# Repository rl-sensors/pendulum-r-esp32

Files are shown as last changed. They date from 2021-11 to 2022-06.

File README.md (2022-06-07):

# Real-world Implementation of the Swing Up Pendulum

This is an implementation of the swing up pendulum for [ESP32S2](https://www.sparkfun.com/products/17743) board for Deep Reinforcement Learning training.

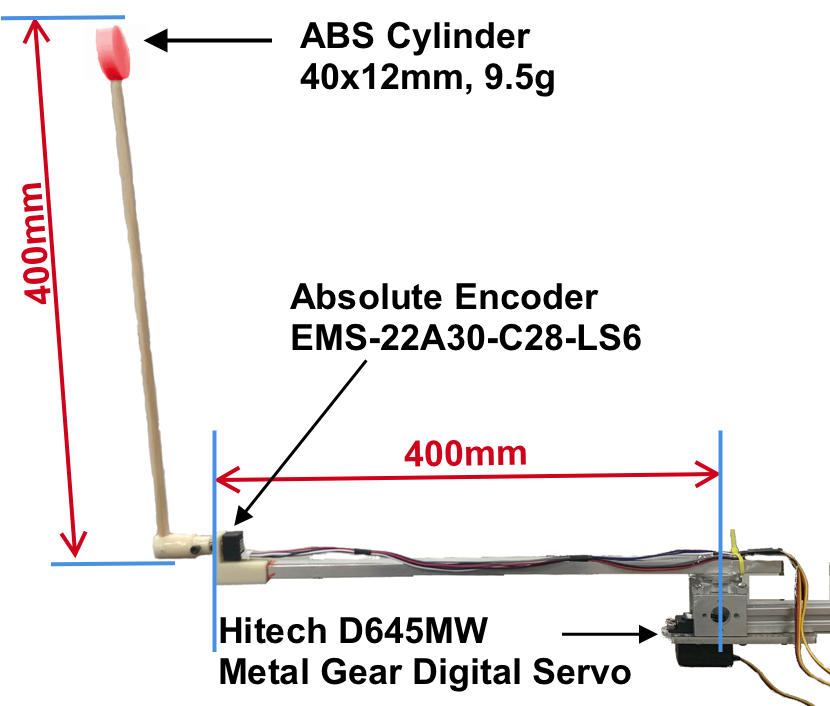
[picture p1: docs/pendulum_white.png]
Pendulum


The CAD file with parts to be 3D printed is in [docs folder](docs/pendulum_r_sim.FCStd) (requires FreeCAD). They are encoder mount, pendulum coupler and the weight cylinder. 
We used ABS filament with 100% in-fill. Despite that, both the encoder mount and the coupler broke during the experiments.

The arm is made of aluminium rectangle tube 20x10x2mm and the pendulum is made of 8mm pine dowel.

The servo is mounted using a servo block - [they are available in the US](https://www.gobilda.com/servoblock-standard-size-25-tooth-spline-hub-shaft/) - we used a custom made block.

### Communication with DRL Training
It uses MQTT protocol for communication (over WiFi).
The observations are streamed to `pendulum-r/obs/r01` and the actions need to be streamed to `pendulum-r/act/r01`.

### Building and Uploading
This is a [PlatformIO](https://platformio.org) project, so it requires platformIO to be installed.

Because the ESP32S2 is not yet fully supported, it requires a custom toolchain. 

For platformIO, find the toolchain in the [JSON file](https://raw.githubusercontent.com/espressif/arduino-esp32/gh-pages/package_esp32_index.json) from the __Installing using Boards Manager__ section.
Look for section `xtensa-esp32s2-elf-gcc` and download the toolchain for your platform.

Untar the file and copy the above JSON file inside and rename it to `package.json`.

Update the `platformio.ini` file to include:

    board_build.mcu = esp32s2
    platform_packages =
        toolchain-xtensa32s2@file:///home/xxx/install/xtensa-esp32s2-elf
        framework-arduinoespressif32@https://github.com/espressif/arduino-esp32.git#44c11981d2159565c551028f2498f65764607f74
        platformio/tool-esptoolpy @ ~1.30100

Basically, the toolchain-xtensa32s2 points to the dir with the downloaded toolchain.

The `framework-arduinoespressif32` section points to the github (the #44c11 is hash of version 2.0)

After that it's just:

    pio project init
    platformio run --target upload -e esp32thing_plus

Alternatively, you can use one of the supported IDEs like CLion or Visual Studio.

## Code
### Main
We are using Arduino rather than ESP-IDF (because the original version use Teensy 4.0), there are 2 main methods - `setup()` and `loop()`.
The first runs initialization code and the second is called repeatedly.

### Encoder
The encoder used is a low cost absolute encoder [EMS-22A30-C28-LS6](https://www.digikey.com/en/products/detail/bourns-inc/EMS22A30-C28-LS6/3693519).
It requires custom protocol for reading the values. It is implemented in [BournsEncoder.h](include/BournsEncoder.h).
The final reading used for training is mean of the last 3 readings (implemented through circular buffer).

### Servo Shield
The servo [Hitec D645MW](https://hitecrcd.com/products/servos/sport-servos/digital-sport-servos/d645mw/product) is controlled through [servo shield](https://www.adafruit.com/product/815).
This allows the MCU and servo to be powered separately and protect the MCU when servo fails (which does happen every few hundreds hours of operation).

We experimented with different servos - with varying success. The D645MW is very smooth and has a good holding torque and it's quite durable.
We were able to train with Turnigy TGY-WP23 as well but it oscillates and breaks quite fast.
We also tried [HSB-9380TH](https://hitecrcd.com/products/servos/digital/brushless-digital/hsb-9380th-ultra-torque-brushless-titanium-gear-servo/product) but it was not possible to even start training because it developed powerful oscillation.

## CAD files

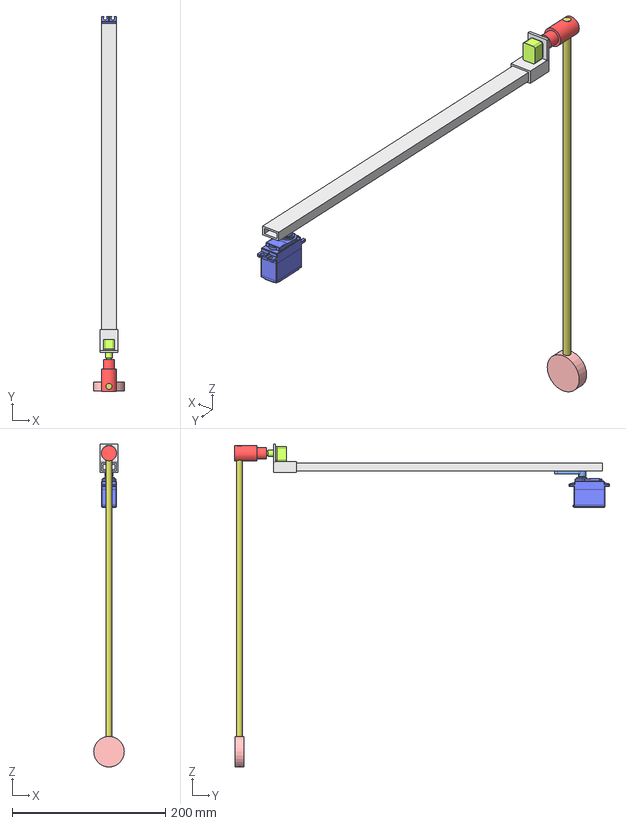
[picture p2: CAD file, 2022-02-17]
docs/pendulum_r_sim.FCStd
40.0 x 490.5 x 422.0 mm
Arm
HS-488HB
EMS22A30
PendulumMount
Dowel
PendulumWeight
EncoderMount

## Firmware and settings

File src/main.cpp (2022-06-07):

#include <Arduino.h>
#include "ServoShield.h"
#include "BournsEncoder.h"
#include <Wire.h>

#include <WiFi.h>
#include <MQTT.h>

const char ssid[] = "smc6";
const char pass[] = "nejaketazkeheslo";
const char mqt_ip[] = "192.168.86.202";

WiFiClient net;
MQTTClient client;

String showText;
int position_update = 0;
unsigned long lastMillis = 0;
int lastPosition = 0;

unsigned long dataSentTS, lastActionTS = millis();
int encoder_offset = 31; // with the ABS coupler (with the line)

bool sendData = false;
bool autoSendData = false;
bool continuousActionSpace = false;

constexpr float throttleSpeed = 2.0;

int streaming_delay = 25;
int acting_delay = 10;

constexpr int setupNo = 1;

String observationsTopic = String("pendulum-r/obs/r0") + setupNo;
String actionsTopic = String("pendulum-r/act/r0") + setupNo;

void connect();
void getBTData(String &topic, String &payload);

void setup() {
  Serial.begin(115200);
  delay(2000);
  Serial.println("Starting...");

  Wire.begin(1, 2); // ESP32S2
  Wire.setClock(400000);

  WiFi.begin(ssid, pass);

  ServoShield::init();
//  BournsEncoder::init(32, 15, 33); // ESP32
//   BournsEncoder::init(8, 4, 6); //ESP32S2 - P2
  BournsEncoder::init(6, 8, 10); //ESP32S2 - P1

  // Note: Local domain names (e.g. "Computer.local" on OSX) are not supported
  // by Arduino. You need to set the IP address directly.
  client.begin(mqt_ip, net);
  client.onMessage(getBTData);

  connect();

  Serial.print("Listening on ");
  Serial.println(actionsTopic);
  Serial.print("Observations on ");
  Serial.println(observationsTopic);
}

void loop() {
  client.loop();
  // delay(1);  // <- fixes some issues with WiFi stability

  unsigned long newMillis = millis();

  // this block takes about 5ms
  if ((sendData || (autoSendData && (newMillis - dataSentTS > streaming_delay)))) {
    // this call takes 3ms
    BournsEncoder::read();
    // Serial.print("Bourns reading took: ");
    // Serial.println(millis() - newMillis);

    int time_delta = (int) (newMillis - lastMillis);
    lastMillis = newMillis;

    int position = (BournsEncoder::position + encoder_offset) % 1024;
    float velocity = (position - lastPosition) / time_delta;
    lastPosition = position;

    char state[100] = ""; // without the initialization it contains new lines and unprintable chars
    sprintf(state, "S%ld,%d,%d,%f,%f,%f",
            newMillis,
            position,
            ServoShield::pulselen,
            BournsEncoder::omegas.average(),
            BournsEncoder::acceleration,
            velocity
    );

    Serial.println(state);
    client.publish(observationsTopic, state);
    dataSentTS = newMillis;

    if (sendData) {
      sendData = false;
    }

     // Serial.print("Sending data took: ");
     // Serial.println(millis() - newMillis);
  }

  newMillis = millis();
  // throttle when omega is over 2 rotations per second
  if (!continuousActionSpace && newMillis - lastActionTS > acting_delay) {
    if (fabs(BournsEncoder::omegas.average()) > throttleSpeed) {
      position_update = ServoShield::STOP;
    }
    ServoShield::move(position_update);
    lastActionTS = newMillis;
  }
}

void connect() {
  Serial.print("checking wifi...");
  while (WiFi.status() != WL_CONNECTED) {
    Serial.print(".");
    delay(1000);
  }

  String clientId = String("pendulum_r_prod_s") + setupNo;

  Serial.print("\nconnecting...");
  while (!client.connect(clientId.c_str(), "public", "public")) {
    Serial.print(".");
    delay(1000);
  }

  Serial.println("\nconnected!");

  client.subscribe(actionsTopic);
}


void getBTData(String &topic, String &payload) {
  Serial.print("Received command: ");
  Serial.println(payload);

  char dir = payload.charAt(0);

  switch(dir) {
    case 'a':
      position_update = -ServoShield::FAST;
      break;
    case 's':
      position_update = -ServoShield::SLOW;
      break;
    case 'd':
      position_update = ServoShield::STOP;
      break;
    case 'f':
      position_update = ServoShield::SLOW;
      break;
    case 'g':
      position_update = ServoShield::FAST;
      break;
    case 'm':
      position_update = payload.substring(1).toInt();
      break;
    case 'o':
      encoder_offset = atoi(payload.substring(1).c_str());
      break;
    case 'u':
      streaming_delay = atoi(payload.substring(1).c_str());
      break;
    case 'i':
      acting_delay = atoi(payload.substring(1).c_str());
      break;
    case 'z':
      sendData = true;
      break;
    case 'x':
      autoSendData = true;
      break;
    case 'y':
      autoSendData = false;
      break;
    case 'c':
      continuousActionSpace = true;
      break;
    case 'v':
      continuousActionSpace = false;
      break;
    case 'e':
      ServoShield::EXP_FILTER_C = atof(payload.substring(1).c_str());
      break;
    case 'b':
      if (fabs(BournsEncoder::omegas.average()) <= throttleSpeed) {
        ServoShield::set_action(atof(payload.substring(1).c_str()));
      }
      break;

//      case 'p':
//        showText = cmd.substring(1);
//        Lcd::print_short(showText);
//        break;
    default: break; // keep the current course
  }
}

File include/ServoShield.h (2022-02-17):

//
// Created by bohm on 11/8/21.
//

#ifndef PENDULUM_R_ESP32_SERVOSHIELD_H
#define PENDULUM_R_ESP32_SERVOSHIELD_H

#include <Arduino.h>
#include <Wire.h>
#include <Adafruit_PWMServoDriver.h>

namespace ServoShield {
  Adafruit_PWMServoDriver pwm = Adafruit_PWMServoDriver(0x40);

  #define SERVO_FREQ 50 // Analog servos run at ~50 Hz updates

  // for turnigy 200 and 400
  #define SERVOMIN  200 // This is the 'minimum' pulse length count (out of 4096)
  #define SERVOMAX  400 // This is the 'maximum' pulse length count (out of 4096)

  // for HiTec 9380TH
//  #define SERVOMIN  150 // This is the 'minimum' pulse length count (out of 4096)
//  #define SERVOMAX  450 // This is the 'maximum' pulse length count (out of 4096)
//  #define SERVO_FREQ 50 // Analog servos run at ~50 Hz updates

  // turningy
  static constexpr int  SLOW = 1;
  static constexpr int  FAST = 2;

  float EXP_FILTER_C = 0.9;

    // HiTec
//  static constexpr int  SLOW = 2;
//  static constexpr int  FAST = 4;


  static constexpr int  STOP = 0;

  constexpr uint8_t servonum = 4;

  volatile int pulselen = (SERVOMAX - SERVOMIN) / 2 + SERVOMIN;

  void init() {
    pwm.begin();

    pwm.setPWMFreq(SERVO_FREQ);  // Analog servos run at ~50 Hz updates

    delay(10);

    pwm.setPWM(servonum, 0, pulselen);
  }

  void move(int &position_update) {
    if (pulselen + position_update <= SERVOMAX && pulselen + position_update >= SERVOMIN)  {
      pulselen += position_update;
      //position_update = 0;
    } else {
      //position_update = 0;
    }

    pwm.setPWM(servonum, 0, pulselen);
  }

    void set_position_with_filter(int const &new_position_cmd) {
      int old_position = pulselen;
      int new_position = old_position * EXP_FILTER_C + new_position_cmd * (1.0 - EXP_FILTER_C);
      if (new_position <= SERVOMIN) {
        pulselen = SERVOMIN;
      } else if (new_position >= SERVOMAX) {
        pulselen = SERVOMAX;
      } else {
        pulselen = new_position;
      }

      pwm.setPWM(servonum, 0, pulselen);
    }

    void set_action(float const &new_position_cmd) {
      int position = map(
              new_position_cmd * 1000, -1000.0, 1000.0,
              SERVOMIN, SERVOMAX
      );
      set_position_with_filter(position);

//    char msg[100] = "";
//    sprintf(msg, "Servo %i: action %f translated to position %i", servonum, new_position_cmd, position);
//    Mqtt::client.publish("quaid01/actions", msg);
    }


}

#endif //PENDULUM_R_ESP32_SERVOSHIELD_H

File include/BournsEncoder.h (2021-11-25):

//
// Created by bohm on 11/8/21.
//

#ifndef PENDULUM_R_ESP32_BOURNSENCODER_H
#define PENDULUM_R_ESP32_BOURNSENCODER_H

#include "circular_buffer.h"

namespace BournsEncoder {
  int PIN_CS = 32;
  int PIN_CLOCK = 15;
  int PIN_DATA = 33;

  const int bourns_delay = 1;

  volatile int position = 0;

  int lastPosition = 0;
  int delta = 0;
  unsigned long lastUpdated, now = millis();

  static constexpr int OMEGAS_COUNT = 4;
  Circular_Buffer<double, OMEGAS_COUNT> omegas;
  double acceleration = 0;

  byte stream[16] = {0};//replace testStream with stream for actual data


  void init(int cs_pin, int clock_pin, int data_pin) {
    PIN_CS = cs_pin;
    PIN_CLOCK = clock_pin;
    PIN_DATA = data_pin;

    pinMode(PIN_CS, OUTPUT);
    pinMode(PIN_CLOCK, OUTPUT);
    pinMode(PIN_DATA, INPUT);

    digitalWrite(PIN_CLOCK, HIGH);
    digitalWrite(PIN_CS, LOW);
  }

  void read() {
    digitalWrite(PIN_CS, HIGH);
    delayMicroseconds(bourns_delay);
    digitalWrite(PIN_CS, LOW);

    stream[16] = {0};
    for (int i = 0; i < 16; i++) {
      digitalWrite(PIN_CLOCK, LOW);
      delayMicroseconds(bourns_delay);
      digitalWrite(PIN_CLOCK, HIGH);
      delayMicroseconds(bourns_delay);

      stream[i] = digitalRead(PIN_DATA);
    }

    digitalWrite(PIN_CLOCK, LOW);
    digitalWrite(PIN_CLOCK, HIGH);

    //extract 10 bit position from data stream use testStream
    position = 0; //clear previous data
    for (int i = 0; i < 10; i++) {
      position = position << 1;
      position += stream[i];
    }

    delta = position - lastPosition;
    if (abs(delta) > 512) {
      delta = 1024 - abs(delta);
      if (position > lastPosition) {
        delta *= -1;
      }
    }
    lastPosition = position;
    now = millis();
    double timeDelta = (double)(now - lastUpdated);
    lastUpdated = now;

    omegas.push_back(delta / timeDelta / 1.024); // rotations per sec
    acceleration = (omegas[OMEGAS_COUNT - 1] - omegas[OMEGAS_COUNT - 2]) / timeDelta;
    /*
    Serial.print("Delta ENc: ");
    Serial.print(delta);
    Serial.print(" Delta T: ");
    Serial.print((double) (now - lastUpdated));
    Serial.print(" Omega size: ");
    Serial.print(omegas.size());
    Serial.print(" Omega: ");
    Serial.println(delta / (double) (now - lastUpdated) / 1.024);
    */

  }
}

#endif //PENDULUM_R_ESP32_BOURNSENCODER_H

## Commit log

2021-11-08 Added servo library and circular buffer
2021-11-08 Added servo shield functions from the teensy project
2021-11-08 Added bourns encoder reading lib
2021-11-08 Copied the teensy version (uses serial communication)
2021-11-09 Added new line to observations printing to Serial
2021-11-09 Updated encoder pins
2021-11-14 Added acting delay - without it the repeated actions are executed too fast
    [main.cpp]
2022-01-14 Added the cad work
    [pendulum_r_sim.FCStd]
2022-02-17 Updates for esp32s2
